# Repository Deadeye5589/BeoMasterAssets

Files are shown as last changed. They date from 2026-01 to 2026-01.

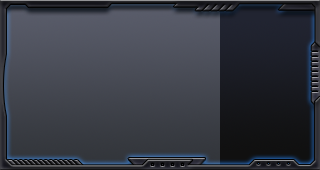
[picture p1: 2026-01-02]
SquareLineStudio/assets/Display_Left.png

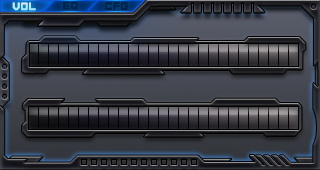
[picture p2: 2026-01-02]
SquareLineStudio/assets/Display_Right_vol_bg.png

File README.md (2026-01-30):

This repo consists of files needed for the BeoMaster Amp project.
It includes
Schematic and layout for main DSP PCB
Schematic and layout for 230 V power distribution PCB
Fusion360 and SVG files to lasercut front display construction
PDS files for left and right display graphics
Square Line Studio projects for left and right display content

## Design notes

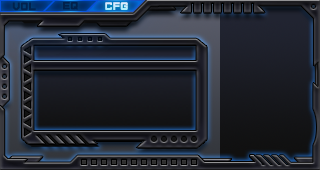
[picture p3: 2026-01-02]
SquareLineStudio/assets/Display_Right_VU_bg.png

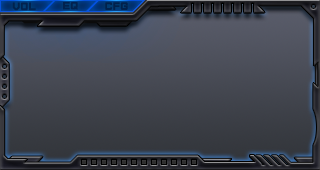
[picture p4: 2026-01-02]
SquareLineStudio/assets/Display_Right_bg.png

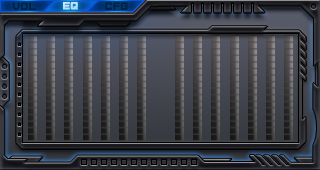
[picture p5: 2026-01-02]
SquareLineStudio/assets/Display_Right_eq_bg.png

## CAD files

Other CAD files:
CAD/Amp+Grundplatte_v3.f3d
CAD/BeoMasterBlende.f3d

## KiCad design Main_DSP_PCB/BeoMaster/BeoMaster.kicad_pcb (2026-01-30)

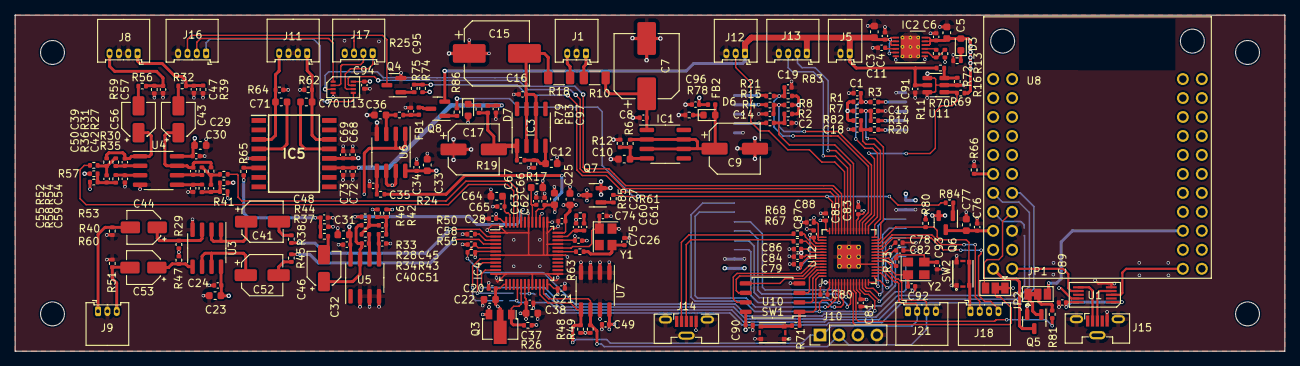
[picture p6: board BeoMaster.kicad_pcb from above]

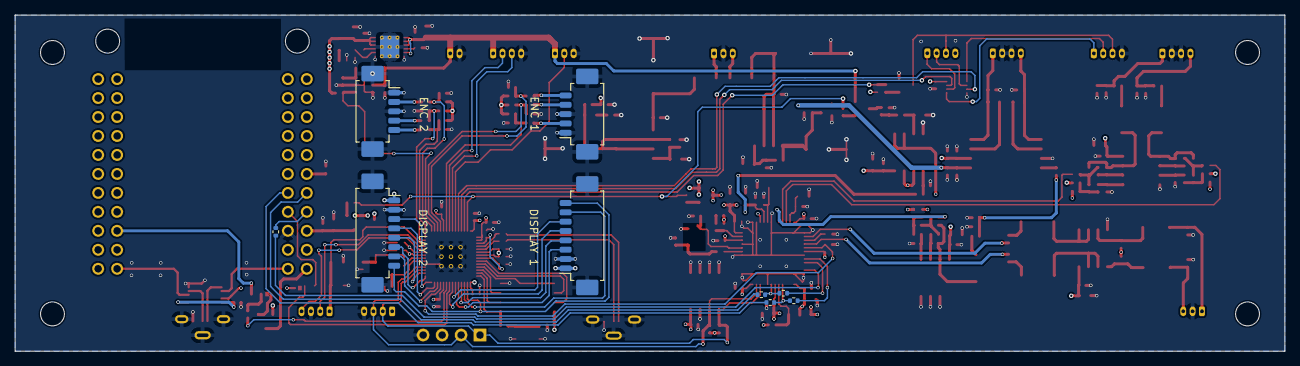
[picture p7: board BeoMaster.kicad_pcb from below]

Board: 4 copper layers, 170.0 x 45.0 mm, 238 parts (9 on the bottom side), 160 nets.

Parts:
C1, C2, C4, C6, C13, C14, C18, C19, C20, C21, C24, C26, C27, C28, C30, C32, C34, C35, C38, C49, C58, C63, C65, C67, C69, C73, C76, C89: 100nF; C_0402_1005Metric
C3, C5, C10, C12, C22, C23, C25, C29, C31, C33, C37, C62, C64, C66, C70, C71, C77: 10µF; C_0603_1608Metric
C7, C15: 220µF; CP_Elec_8x10.5
C8, C16: 220nF; C_0402_1005Metric
C9, C17: 100µF; CP_Elec_6.3x5.8
C11, C95, C96, C97: 10nF; C_0402_1005Metric
C36: 2.2µF; C_0603_1608Metric
C39, C40, C50, C51, C54, C59: 150pF; C_0402_1005Metric
C41, C52: 47µF; CP_Elec_5x5.8
C42, C45, C55: 1nF; C_0402_1005Metric
C43, C46, C56: 10µF; CP_Elec_4x5.4
C44, C53: 2.2µF; CP_Elec_4x5.4
C47, C48, C57, C60: 3n3; C_0402_1005Metric
C61: 56nF; C_0402_1005Metric
C68, C72: 1µF; C_0402_1005Metric
C74, C75: 18pF; C_0402_1005Metric
C78, C79, C80, C81, C82, C83, C84, C85, C86, C90, C91, C94: 100n; C_0402_1005Metric
C87, C88: 1u; C_0402_1005Metric
C92, C93: 18p; C_0402_1005Metric
D3, D6, D7: LED; LED_0603_1608Metric
FB1, FB2, FB3: 300@1MHz; L_0402_1005Metric
H1, H2, H3, H4: MountingHole; MountingHole_3.2mm_M3_ISO14580
IC1: LM317L_SO8; SOIC-8_3.9x4.9mm_P1.27mm
IC2: LP38798; WSON-12-1EP_4x4mm_P0.5mm_EP2.6x3mm_ThermalVias
IC3: LM337L_SO8; SOIC-8_3.9x4.9mm_P1.27mm
IC4: ADAU1701JSTZ; LQFP-48_7x7mm_P0.5mm
IC5: DRV134UA; SOIC127P1030X265-16N
J1: 24V_In; Molex_PicoBlade_53048-0310_1x03_P1.25mm_Horizontal
J2: Encoder_Links; Molex_PicoBlade_53261-0571_1x05-1MP_P1.25mm_Horizontal
J3: Encoder_Rechts; Molex_PicoBlade_53261-0571_1x05-1MP_P1.25mm_Horizontal
J4: Display_Links; Molex_PicoBlade_53261-0871_1x08-1MP_P1.25mm_Horizontal
J5: 5V_In; Molex_PicoBlade_53048-0210_1x02_P1.25mm_Horizontal
J6: Display_Rechts; Molex_PicoBlade_53261-0871_1x08-1MP_P1.25mm_Horizontal
J8: Audio_Out; Molex_PicoBlade_53048-0410_1x04_P1.25mm_Horizontal
J9: Aux_In; Molex_PicoBlade_53048-0310_1x03_P1.25mm_Horizontal
J10: DSP_Debugger; PinHeader_1x04_P2.54mm_Vertical
J11: Diff_Out; Molex_PicoBlade_53048-0410_1x04_P1.25mm_Horizontal
J12: WS2812; Molex_PicoBlade_53048-0310_1x03_P1.25mm_Horizontal
J13: 220V_Relais; Molex_PicoBlade_53048-0410_1x04_P1.25mm_Horizontal
J14: RPI_USB; USB_Micro-B_Molex-105133-0031
J15: USB_Audio; USB_Micro-B_Molex-105133-0031
J16: AMP_CTRL1; Molex_PicoBlade_53048-0410_1x04_P1.25mm_Horizontal
J17: AMP_CTRL2; Molex_PicoBlade_53048-0410_1x04_P1.25mm_Horizontal
J18: RP_SWD; Molex_PicoBlade_53048-0410_1x04_P1.25mm_Horizontal
J21: I2C_TempSensor; Molex_PicoBlade_53048-0410_1x04_P1.25mm_Horizontal
JP1, JP2: SolderJumper_3_Bridged12; SolderJumper-3_P1.3mm_Bridged12_Pad1.0x1.5mm
Q3: ZXTP25040DZTA; SOT-89-3
Q4: BC816H; SOT-23
Q5, Q6, Q7, Q8: IRLML2244; SOT-23
R1, R2, R3, R4, R7, R8, R14, R15, R20, R21, R26, R31, R34, R36, R43, R54, R58, R65, R71, R73, R75, R82, R83: 1k; R_0402_1005Metric
R6, R19, R62, R64: 220; R_0402_1005Metric
R10, R18: 100; R_1206_3216Metric
R11: 23k7; R_0402_1005Metric
R12, R17: 2k; R_0402_1005Metric
R13: 180; R_0402_1005Metric
R16: 13k3; R_0402_1005Metric
R24, R30, R33, R35, R42, R53, R55, R57, R66, R69, R70, R74, R80: 10k; R_0402_1005Metric
R25, R29, R47: 100k; R_0402_1005Metric
R27, R28, R41, R46, R52, R60: 22k; R_0402_1005Metric
R32, R37, R56: 680; R_0402_1005Metric
R38, R45, R72: 18k; R_0402_1005Metric
R39, R40, R44, R51, R59: 47k; R_0402_1005Metric
R48, R49: 2k2; R_0402_1005Metric
R50: 18k2; R_0402_1005Metric
R61: 475; R_0402_1005Metric
R63, R81, R84, R85, R86: 100; R_0402_1005Metric
R67, R68: 27; R_0402_1005Metric
R78, R79: 820; R_0402_1005Metric
R87, R88, R89, R90, R91: 22; R_0402_1005Metric
SW1: BOOT; SKSG
SW2: RESET; SKSG
U1: TS3USB30E; TEXAS_VSSOP_10_P0.5
U3, U4, U5, U6: LME49720; SOIC-8_3.9x4.9mm_P1.27mm
U7: 24LC256 (SN); SOIC-8_3.9x4.9mm_P1.27mm
U8: CSRA64215; CSR64215
U10: W25Q128JVS; SOIC-8_5.23x5.23mm_P1.27mm
U11: TPS3711; SOT-23-6
U12: RP2040; RP2040-QFN-56
U13: NC7WZ38; US8 -OnSemi
Y1: 12.288MHz; Crystal_SMD_3225-4Pin_3.2x2.5mm
Y2: 12 MHz; Crystal_SMD_3225-4Pin_3.2x2.5mm

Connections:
+1V1: C78.1, C79.1, C87.1, U12.23 (DVDD), U12.45 (VREG_VOUT), U12.50 (DVDD)
+1V5: R35.1, R42.1, R57.1, U6.6 (-), U6.7
+1V8: C20.1, C21.1, C22.1, IC4.13 (DVDD), IC4.24 (DVDD), Q3.2 (C)
+3.3VP: C25.1, C26.1, C27.1, C28.1, C37.1, C38.1, C49.1, C60.2, IC4.6 (SELFBOOT), IC4.18 (IOVDD), IC4.34 (PVDD), IC4.36 (AVDD), IC4.39 (PLL_MOD1), IC4.48 (AVDD), Q3.3 (E), Q7.3 (D), R26.1, R48.1, R49.1, R55.1, R61.1, U7.8 (VCC)
+3V3: C5.1, C6.1, C80.1, C81.1, C82.1, C83.1, C84.1, C85.1, C86.1, C88.1, C89.1, C90.1, C94.1, D3.2 (A), IC2.10 (OUT_(FB)), IC2.11 (OUT), IC2.12 (OUT), J4.1, J6.1, J21.1, Q5.2 (S), Q6.2 (S), Q7.2 (S), R1.2, R2.2, R7.2, R8.2, R69.1, R74.1, R80.1, R82.2, R83.2, U1.1 (S), U1.10 (Vcc), U10.8 (VCC), U12.1 (IOVDD), U12.10 (IOVDD), U12.22 (IOVDD), U12.33 (IOVDD), U12.42 (IOVDD), U12.43 (ADC_AVDD), U12.44 (VREG_IN), U12.48 (USB_VDD), U12.49 (IOVDD), U13.8 (Vcc)
+5V: C3.1, C4.1, C91.1, IC2.1 (IN), IC2.2 (IN), IC2.3 (IN_(CP)), IC2.5 (EN), J5.1, J12.1, J13.1, Q8.2 (S), R70.1, U11.5 (VDD)
+5VA: R29.1, R41.2, R46.2, R47.1, R60.2, U6.1, U6.2 (-)
+12V: C23.1, C24.1, C29.1, C30.1, C31.1, C32.1, C33.1, C34.1, C68.1, C69.1, C96.1, FB2.2, IC5.12 (V+), U3.8 (V+), U4.8 (V+), U5.8 (V+), U6.8 (V+)
-12V: C72.2, C73.2, C97.2, FB3.2, IC5.11 (V-)
/AMP_MUTE: R74.2, R75.2, U12.40 (GPIO28_ADC2)
/QSPI_SCLK: U10.6 (CLK), U12.52 (QSPI_SCLK)
/QSPI_SD0: U10.5 (DI(IO0)), U12.53 (QSPI_SD0)
/QSPI_SD1: U10.2 (DO(IO1)), U12.55 (QSPI_SD1)
/QSPI_SD2: U10.3 (IO2), U12.54 (QSPI_SD2)
/QSPI_SD3: U10.7 (IO3), U12.51 (QSPI_SD3)
/QSPI_SS: R71.1, U10.1 (~CS), U12.56 (QSPI_SS)
/RUN: J18.1, R80.2, SW2.2, U12.26 (RUN)
/SSR1: J13.2, U12.35 (GPIO23)
/SSR2: J13.3, U12.36 (GPIO24)
/SWCLK: J18.4, U12.24 (SWCLK)
/SWD: J18.2, U12.25 (SWD)
/USB_D+: J14.3 (D+), R67.1
/USB_D-: J14.2 (D-), R68.1
/USB_N: U1.7 (D2-), U8.2 (USBN)
/USB_P: U1.3 (D2+), U8.23 (USBP)
/V_SENS: R69.2, U11.1 (OUT), U12.30 (GPIO19)
/Vin+: J1.1, R10.1
/Vin-: J1.3, R18.1
/XIN: C92.1, U12.20 (XIN), Y2.1
/XOUT: R73.1, U12.21 (XOUT)
/~USB_BOOT: R71.2, SW1.2
AMP_MUTE_CONN: J16.3, J17.3, Q4.3 (C)
AMP_OC: U12.39 (GPIO27_ADC1), U13.7 (Y1)
AMP_TEMP: U12.38 (GPIO26_ADC0), U13.3 (Y2)
Analog_In0: IC4.45 (VOUT1), R30.1
Analog_In1: IC4.46 (VOUT0), R53.1
Analog_Out0: C47.1, J8.1, R32.2, R39.1
Analog_Out1: C57.1, J8.4, R56.2, R59.1
BCLK: R90.2, U8.9 (CLK)
BT_MFB: R81.1, U12.9 (GPIO7)
BT_RST: JP2.2 (C), U12.8 (GPIO6)
CM: C62.1, C63.1, IC4.40 (CM), R24.2
DISP_BL: J4.8, J6.8, U12.2 (GPIO0)
DISP_CLK1: J4.4, U12.13 (GPIO10)
DISP_CLK2: J6.4, U12.4 (GPIO2)
DISP_CS1: J4.5, U12.16 (GPIO13)
DISP_CS2: J6.5, U12.7 (GPIO5)
DISP_DC1: J4.6, U12.15 (GPIO12)
DISP_DC2: J6.6, U12.6 (GPIO4)
DISP_DIN1: J4.3, U12.14 (GPIO11)
DISP_DIN2: J6.3, U12.5 (GPIO3)
DISP_RST1: J4.7, U12.12 (GPIO9)
DISP_RST2: J6.7, U12.3 (GPIO1)
DSP_RESET: C58.1, IC4.5 (~RESET), J10.3, R55.2, U12.11 (GPIO8)
Diff_In0: IC4.44 (VOUT2), R33.1
Diff_Out0: C48.1, R37.2, R44.1, R65.2
Diff_Out0+: C70.1, IC5.14 (+Vo), J11.1, R62.1
Diff_Out0-: C71.2, IC5.3 (-Vo), J11.4, R64.2
ENC1_A: C13.1, R7.1, R14.2, U12.27 (GPIO16)
ENC1_B: C18.1, R20.2, R82.1, U12.28 (GPIO17)
ENC1_SW: C1.1, R1.1, R3.2, U12.29 (GPIO18)
ENC2_A: C14.1, R8.1, R15.2, U12.31 (GPIO20)
ENC2_B: C19.1, R21.2, R83.1, U12.32 (GPIO21)
ENC2_SW: C2.1, R2.1, R4.2, U12.34 (GPIO22)
GND: C1.2, C2.2, C3.2, C4.2, C5.2, C6.2, C7.2, C8.2, C9.2, C10.2, C11.2, C12.2, C13.2, C14.2, C15.1, C16.2, C17.1, C18.2, C19.2, C20.2, C21.2, C22.2, C23.2, C24.2, C25.2, C26.2, C27.2, C28.2, C29.2, C30.2, C31.2, C32.2, C33.2, C34.2, C35.2, C36.2, C37.2, C38.2, C47.2, C48.2, C49.2, C50.2, C51.2, C57.2, C58.2, C59.2, C62.2, C63.2, C64.2, C65.2, C66.2, C67.2, C68.2, C69.2, C72.1, C73.1, C74.2, C75.2, C76.2, C77.2, C78.2, C79.2, C80.2, C81.2, C82.2, C83.2, C84.2, C85.2, C86.2, C87.2, C88.2, C89.2, C90.2, C91.2, C92.2, C93.2, C94.2, C95.2, C96.2, C97.1, D7.2 (A), IC2.6 (GND_(CP)), IC2.7 (GND), IC2.13 (EP), IC4.1 (AGND), IC4.7 (ADDR0), IC4.12 (DGND), IC4.20 (ADDR1), IC4.25 (DGND), IC4.30 (RSVD), IC4.33 (PGND), IC4.37 (AGND), IC4.38 (PLL_MOD0), IC4.42 (AGND), IC5.5 (GND), J1.2, J2.1, J2.3, J2.MP, J3.1, J3.3, J3.MP, J4.2, J4.MP, J5.2, J6.2, J6.MP, J8.2, J8.3, J9.2, J10.4, J11.2, J11.3, J12.3, J13.4, J14.5 (GND), J14.6 (Shield), J15.5 (GND), J15.6 (Shield), J16.4, J18.3, J21.4, Q4.2 (E), R12.2, R13.2, R16.2, R17.1, R39.2, R40.2, R44.2, R50.2, R51.2, R59.2, R62.2, R64.1, R66.2, R72.2, R78.2, SW1.1, SW2.1, U1.5 (GND), U3.4 (V-), U4.4 (V-), U5.2 (-), U5.3 (+), U5.4 (V-), U6.4 (V-), U7.1 (A0), U7.2 (A1), U7.3 (A2), U7.4 (GND), U7.7 (WP), U8.6 (GND), U10.4 (GND), U11.2 (GND), U11.4 (GND), U11.6 (GND), U12.19 (TESTEN), U12.57 (GND), U13.4 (GND), Y1.4
LRCLK: R91.2, U8.10 (CSB)
unnamed: C15.2, C16.1, IC3.2 (VI), IC3.3 (VI), IC3.6 (VI), IC3.7 (VI), R18.2
unnamed: C39.1, C43.1, R27.1, U4.7
unnamed: C40.1, C46.1, R28.1, U5.7
unnamed: C41.2, R38.2
unnamed: C42.1, R27.2, R30.2, R31.1
unnamed: C42.2, R35.2, R36.2, R41.1
unnamed: C43.2, R32.1
unnamed: C45.1, R28.2, R33.2, R34.1
unnamed: C45.2, R42.2, R43.2, R46.1
unnamed: C46.2, R37.1
unnamed: C52.2, R45.2
unnamed: C54.1, C56.1, R52.1, U4.1
unnamed: C55.1, R52.2, R53.2, R54.1
unnamed: C55.2, R57.2, R58.2, R60.1
unnamed: C56.2, R56.1
unnamed: C61.2, R61.2
unnamed: C75.1, R63.2, Y1.3
unnamed: C93.1, R73.2, Y2.3
unnamed: C95.1, FB1.2, R25.2
unnamed: D3.1 (K), R13.1
unnamed: C9.1, D6.2 (A), FB2.1, IC1.2 (VO), IC1.3 (VO), IC1.6 (VO), IC1.7 (VO), R6.1
unnamed: D6.1 (K), R78.1
unnamed: D7.1 (K), R79.1
unnamed: C10.1, IC1.4 (ADJ), R6.2, R12.1
unnamed: C7.1, C8.1, IC1.1 (VI), R10.2
unnamed: C11.1, IC2.4 (CP)
unnamed: IC2.8 (FB), R11.2, R16.1
unnamed: IC2.9 (SET), R11.1
unnamed: C12.1, IC3.4 (ADJ), R17.2, R19.1
unnamed: C17.2, FB3.1, IC3.1 (VO), R19.2, R79.2
unnamed: IC4.2 (ADC0), R38.1
unnamed: IC4.4 (ADC1), R45.1
unnamed: IC4.3 (ADC_RES), R50.1
unnamed: C64.1, C65.1, IC4.47 (FILTA)
unnamed: C66.1, C67.1, IC4.41 (FILTD)
unnamed: C74.1, IC4.32 (MCLKI), Y1.1
unnamed: IC4.8 (MP4), R89.1
unnamed: IC4.9 (MP5), R88.1
unnamed: IC4.16 (MP10), R89.2, R91.1
unnamed: IC4.19 (MP11), R88.2, R90.1
unnamed: IC4.31 (OSCO), R63.1
unnamed: C60.1, C61.1, IC4.35 (PLL_LF)
unnamed: IC4.17 (VDRIVE), Q3.1 (B), R26.2
unnamed: C70.2, IC5.13 (+Sense)
unnamed: C71.1, IC5.4 (-Sense)
unnamed: IC5.6 (Vin), R65.1
unnamed: J2.2, R3.1
unnamed: J2.4, R14.1
unnamed: J2.5, R20.1
unnamed: J3.2, R4.1
unnamed: J3.4, R15.1
unnamed: J3.5, R21.1
unnamed: C44.2, J9.1, R40.1
unnamed: C53.2, J9.3, R51.1
unnamed: J15.3 (D+), U1.4 (D+)
unnamed: J15.2 (D-), U1.6 (D-)
unnamed: J16.1, U13.5 (A2)
unnamed: J16.2, U13.1 (A1)
unnamed: J17.1, U13.6 (B2)
unnamed: J17.2, U13.2 (B1)
unnamed: JP1.1 (A), Q5.1 (G)
unnamed: JP1.3 (B), U8.27 (MFB)
unnamed: JP1.2 (C), R81.2
unnamed: JP2.1 (A), U1.9 (~OE)
unnamed: JP2.3 (B), U8.8 (RST)
unnamed: Q4.1 (B), R75.1
unnamed: Q5.3 (D), U8.1 (VCHG)
unnamed: C76.1, C77.1, Q6.3 (D), U8.5 (VBAT)
unnamed: Q6.1 (G), R84.2
unnamed: Q7.1 (G), R85.2
unnamed: FB1.1, Q8.3 (D)
unnamed: Q8.1 (G), R86.2
unnamed: C44.1, R29.2, U3.3 (+)
unnamed: C41.1, U3.1, U3.2 (-)
unnamed: C53.1, R47.2, U3.5 (+)
unnamed: C52.1, U3.6 (-), U3.7
unnamed: C59.1, R58.1, U4.3 (+)
unnamed: C54.2, R54.2, U4.2 (-)
unnamed: C50.1, R36.1, U4.5 (+)
unnamed: C39.2, R31.2, U4.6 (-)
unnamed: C51.1, R43.1, U5.5 (+)
unnamed: C40.2, R34.2, U5.6 (-)
unnamed: C36.1, R25.1, U6.3 (+)
unnamed: C35.1, R24.1, U6.5 (+)
unnamed: R87.1, U8.7 (MISO)
unnamed: R66.1, U8.11 (SPIPCM)
unnamed: R70.2, R72.1, U11.3 (SENSE)
unnamed: R68.2, U12.46 (USB_DM)
unnamed: R67.2, U12.47 (USB_DP)
PWR_EN: R84.1, R85.1, R86.1, U12.41 (GPIO29_ADC3)
SCL: IC4.23 (SCL), J10.2, J21.3, R49.2, U7.6 (SCL), U12.18 (GPIO15)
SDA: IC4.22 (SDA), J10.1, J21.2, R48.2, U7.5 (SDA), U12.17 (GPIO14)
SDATA: IC4.11 (MP0), R87.2
WS2812: J12.2, U12.37 (GPIO25)

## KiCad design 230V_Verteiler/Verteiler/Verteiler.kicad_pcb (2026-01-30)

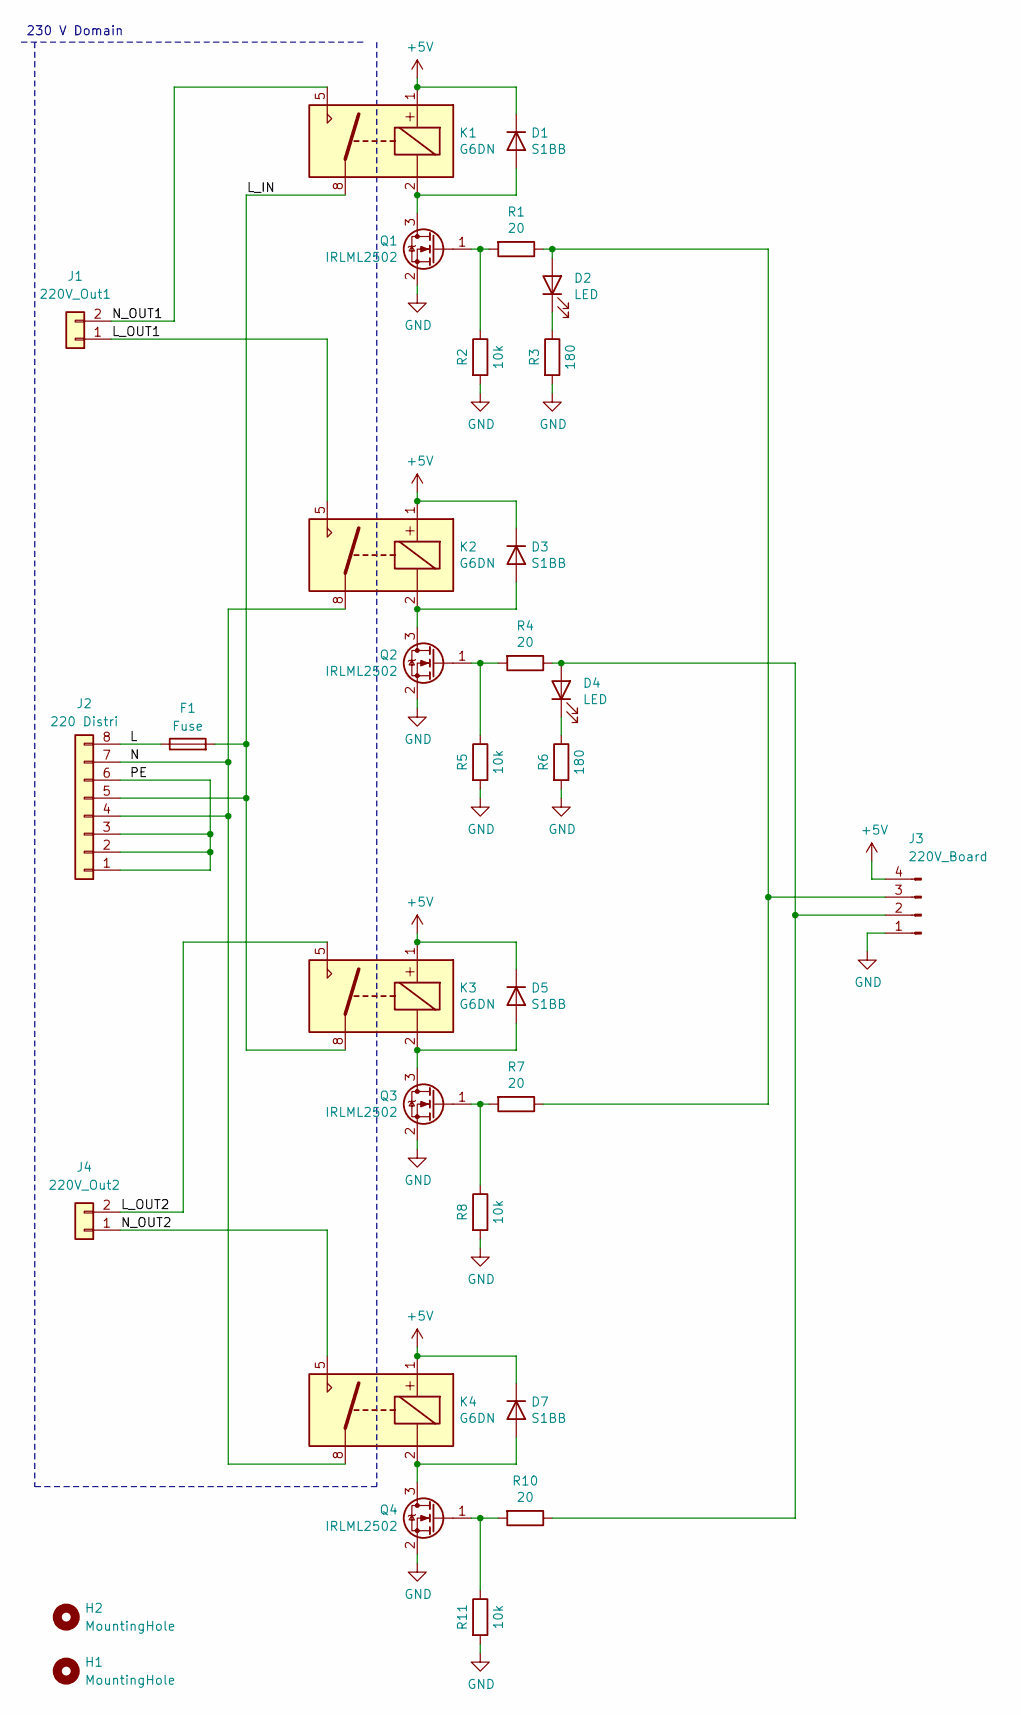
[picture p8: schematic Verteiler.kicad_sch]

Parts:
D1, D3, D5, D7: S1BB; D_SMB
D2, D4: LED; LED_0603_1608Metric
F1: Fuse; Fuseholder_Clip-5x20mm_Littelfuse_111_Lateral_P18.80x5.00mm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
H1, H2: MountingHole; MountingHole_3.2mm_M3
J1: 220V_Out1; PhoenixContact_MSTBA_2,5_2-G-5,08_1x02_P5.08mm_Horizontal
J2: 220 Distri; PhoenixContact_MSTBA_2,5_8-G-5,08_1x08_P5.08mm_Horizontal
J3: 220V_Board; Molex_PicoBlade_53048-0410_1x04_P1.25mm_Horizontal
J4: 220V_Out2; PhoenixContact_MSTBA_2,5_2-G-5,08_1x02_P5.08mm_Horizontal
K1, K2, K3, K4: G6DN
Q1, Q2, Q3, Q4: IRLML2502; SOT-23
R1, R4, R7, R10: 20; R_0402_1005Metric
R2, R5, R8, R11: 10k; R_0402_1005Metric
R3, R6: 180; R_0402_1005Metric

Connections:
+5V: D1.1 (K), D3.1 (K), D5.1 (K), D7.1 (K), J3.4, K1.1, K2.1, K3.1, K4.1
/L: F1.1, J2.8
/L_IN: F1.2, J2.5, K1.8, K3.8
/L_OUT1: J1.1, K2.5
/L_OUT2: J4.2, K3.5
/N: J2.4, J2.7, K2.8, K4.8
/N_OUT1: J1.2, K1.5
/N_OUT2: J4.1, K4.5
/PE: J2.1, J2.2, J2.3, J2.6
GND: J3.1, Q1.2 (S), Q2.2 (S), Q3.2 (S), Q4.2 (S), R2.2, R3.2, R5.2, R6.2, R8.2, R11.2
unnamed: D1.2 (A), K1.2, Q1.3 (D)
unnamed: D2.2 (A), J3.3, R1.1, R7.1
unnamed: D2.1 (K), R3.1
unnamed: D3.2 (A), K2.2, Q2.3 (D)
unnamed: D4.2 (A), J3.2, R4.1, R10.1
unnamed: D4.1 (K), R6.1
unnamed: D5.2 (A), K3.2, Q3.3 (D)
unnamed: D7.2 (A), K4.2, Q4.3 (D)
unnamed: Q1.1 (G), R1.2, R2.1
unnamed: Q2.1 (G), R4.2, R5.1
unnamed: Q3.1 (G), R7.2, R8.1
unnamed: Q4.1 (G), R10.2, R11.1

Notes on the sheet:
230 V Domain

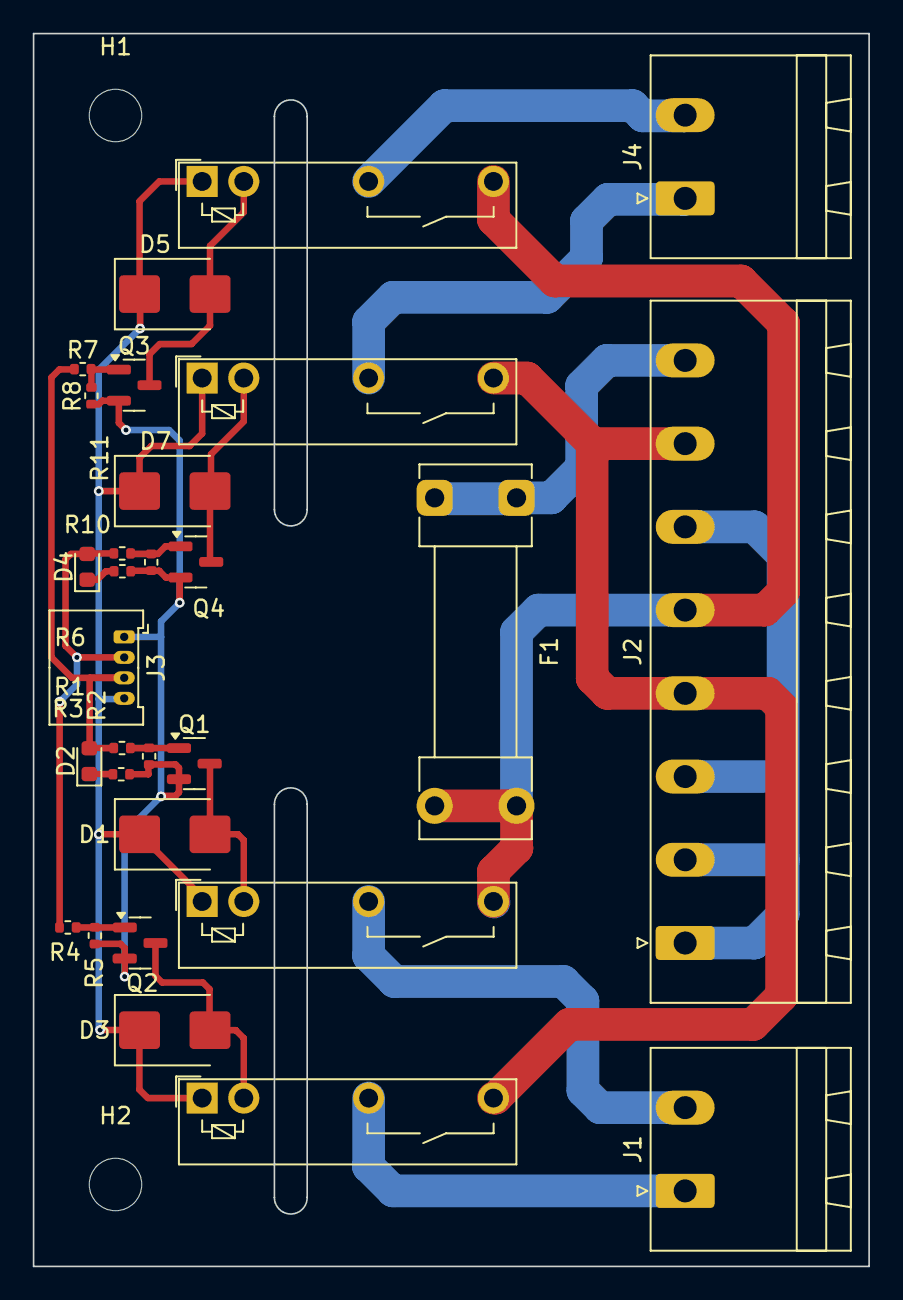
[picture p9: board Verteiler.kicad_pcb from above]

Board: 2 copper layers, 51.0 x 75.2 mm, 31 parts (0 on the bottom side), 22 nets.

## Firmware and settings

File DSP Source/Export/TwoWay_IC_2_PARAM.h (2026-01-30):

/*
 * File:           C:\Users\Succubus\Documents\KiCad\B&O Master\DSP Source\Export\TwoWay_IC_2_PARAM.h
 *
 * Created:        Thursday, December 28, 2023 4:48:27 PM
 * Description:    TwoWay:IC 2 parameter RAM definitions.
 *
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
 * This software may only be used to program products purchased from
 * Analog Devices for incorporation by you into audio products that
 * are intended for resale to audio product end users. This software
 * may not be distributed whole or in any part to third parties.
 *
 * Copyright ©2023 Analog Devices, Inc. All rights reserved.
 */
#ifndef __TWOWAY_IC_2_PARAM_H__
#define __TWOWAY_IC_2_PARAM_H__


/* Module Nx2-1 - Stereo Switch Nx2*/
#define MOD_NX2_1_COUNT                                1
#define MOD_NX2_1_DEVICE                               "IC2"
#define MOD_NX2_1_STEREOSWSLEW_ADDR                    0
#define MOD_NX2_1_STEREOSWSLEW_FIXPT                   0x00000001
#define MOD_NX2_1_STEREOSWSLEW_VALUE                   SIGMASTUDIOTYPE_INTEGER_CONVERT(1)
#define MOD_NX2_1_STEREOSWSLEW_TYPE                    SIGMASTUDIOTYPE_INTEGER

/* Module Single 2_2 - Single Volume*/
#define MOD_SINGLE2_2_COUNT                            2
#define MOD_SINGLE2_2_DEVICE                           "IC2"
#define MOD_SINGLE2_2_ALG0_GAIN1940ALGNS3_ADDR         1
#define MOD_SINGLE2_2_ALG0_GAIN1940ALGNS3_FIXPT        0x00800000
#define MOD_SINGLE2_2_ALG0_GAIN1940ALGNS3_VALUE        SIGMASTUDIOTYPE_FIXPOINT_CONVERT(1)
#define MOD_SINGLE2_2_ALG0_GAIN1940ALGNS3_TYPE         SIGMASTUDIOTYPE_FIXPOINT
#define MOD_SINGLE2_2_ALG1_GAIN1940ALGNS4_ADDR         2
#define MOD_SINGLE2_2_ALG1_GAIN1940ALGNS4_FIXPT        0x00800000
#define MOD_SINGLE2_2_ALG1_GAIN1940ALGNS4_VALUE        SIGMASTUDIOTYPE_FIXPOINT_CONVERT(1)
#define MOD_SINGLE2_2_ALG1_GAIN1940ALGNS4_TYPE         SIGMASTUDIOTYPE_FIXPOINT

/* Module 1 X RTA1 - Single Level Detector*/
#define MOD_1XRTA1_COUNT                               5
#define MOD_1XRTA1_DEVICE                              "IC2"
#define MOD_1XRTA1_ALG0_SINGLEBANDLEVELDET1TCONST_ADDR 3
#define MOD_1XRTA1_ALG0_SINGLEBANDLEVELDET1TCONST_FIXPT 0x00004EB0
#define MOD_1XRTA1_ALG0_SINGLEBANDLEVELDET1TCONST_VALUE SIGMASTUDIOTYPE_FIXPOINT_CONVERT(0.00240140490349172)
#define MOD_1XRTA1_ALG0_SINGLEBANDLEVELDET1TCONST_TYPE SIGMASTUDIOTYPE_FIXPOINT
#define MOD_1XRTA1_ALG0_SINGLEBANDLEVELDET1HOLD_ADDR   4
#define MOD_1XRTA1_ALG0_SINGLEBANDLEVELDET1HOLD_FIXPT  0x000001E0
#define MOD_1XRTA1_ALG0_SINGLEBANDLEVELDET1HOLD_VALUE  SIGMASTUDIOTYPE_INTEGER_CONVERT(480)
#define MOD_1XRTA1_ALG0_SINGLEBANDLEVELDET1HOLD_TYPE   SIGMASTUDIOTYPE_INTEGER
#define MOD_1XRTA1_ALG0_SINGLEBANDLEVELDET1DECAY_ADDR  5
#define MOD_1XRTA1_ALG0_SINGLEBANDLEVELDET1DECAY_FIXPT 0x0000071C
#define MOD_1XRTA1_ALG0_SINGLEBANDLEVELDET1DECAY_VALUE SIGMASTUDIOTYPE_FIXPOINT_CONVERT(0.000217013888888889)
#define MOD_1XRTA1_ALG0_SINGLEBANDLEVELDET1DECAY_TYPE  SIGMASTUDIOTYPE_FIXPOINT
#define MOD_1XRTA1_ALG0_SINGLEBANDLEVELDET1_ADDR       2074
#define MOD_1XRTA1_ALG0_SINGLEBANDLEVELDET1_VALUES     SIGMASTUDIOTYPE_SPECIAL(0x01CE)
#define MOD_1XRTA1_ALG0_SINGLEBANDLEVELDET1_TYPE       SIGMASTUDIOTYPE_SPECIAL
#define MOD_1XRTA1_ALG0_ADDR                           2074
#define MOD_1XRTA1_ALG0_VALUE                          SIGMASTUDIOTYPE_10_14_CONVERT(0)
#define MOD_1XRTA1_ALG0_TYPE                           SIGMASTUDIOTYPE_10_14

/* Module 1 X RTA2 - Single Level Detector*/
#define MOD_1XRTA2_COUNT                               5
#define MOD_1XRTA2_DEVICE                              "IC2"
#define MOD_1XRTA2_ALG0_SINGLEBANDLEVELDET2TCONST_ADDR 6
#define MOD_1XRTA2_ALG0_SINGLEBANDLEVELDET2TCONST_FIXPT 0x00004EB0
#define MOD_1XRTA2_ALG0_SINGLEBANDLEVELDET2TCONST_VALUE SIGMASTUDIOTYPE_FIXPOINT_CONVERT(0.00240140490349172)
#define MOD_1XRTA2_ALG0_SINGLEBANDLEVELDET2TCONST_TYPE SIGMASTUDIOTYPE_FIXPOINT
#define MOD_1XRTA2_ALG0_SINGLEBANDLEVELDET2HOLD_ADDR   7
#define MOD_1XRTA2_ALG0_SINGLEBANDLEVELDET2HOLD_FIXPT  0x000001E0
#define MOD_1XRTA2_ALG0_SINGLEBANDLEVELDET2HOLD_VALUE  SIGMASTUDIOTYPE_INTEGER_CONVERT(480)
#define MOD_1XRTA2_ALG0_SINGLEBANDLEVELDET2HOLD_TYPE   SIGMASTUDIOTYPE_INTEGER
#define MOD_1XRTA2_ALG0_SINGLEBANDLEVELDET2DECAY_ADDR  8
#define MOD_1XRTA2_ALG0_SINGLEBANDLEVELDET2DECAY_FIXPT 0x0000071C
#define MOD_1XRTA2_ALG0_SINGLEBANDLEVELDET2DECAY_VALUE SIGMASTUDIOTYPE_FIXPOINT_CONVERT(0.000217013888888889)
#define MOD_1XRTA2_ALG0_SINGLEBANDLEVELDET2DECAY_TYPE  SIGMASTUDIOTYPE_FIXPOINT
#define MOD_1XRTA2_ALG0_SINGLEBANDLEVELDET2_ADDR       2074
#define MOD_1XRTA2_ALG0_SINGLEBANDLEVELDET2_VALUES     SIGMASTUDIOTYPE_SPECIAL(0x0252)
#define MOD_1XRTA2_ALG0_SINGLEBANDLEVELDET2_TYPE       SIGMASTUDIOTYPE_SPECIAL
#define MOD_1XRTA2_ALG0_ADDR                           2074
#define MOD_1XRTA2_ALG0_VALUE                          SIGMASTUDIOTYPE_10_14_CONVERT(0)
#define MOD_1XRTA2_ALG0_TYPE                           SIGMASTUDIOTYPE_10_14
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

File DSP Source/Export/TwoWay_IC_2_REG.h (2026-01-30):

/*
 * File:           C:\Users\Succubus\Documents\KiCad\B&O Master\DSP Source\Export\TwoWay_IC_2_REG.h
 *
 * Created:        Thursday, December 28, 2023 4:48:27 PM
 * Description:    TwoWay:IC 2 control register definitions.
 *
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
 * This software may only be used to program products purchased from
 * Analog Devices for incorporation by you into audio products that
 * are intended for resale to audio product end users. This software
 * may not be distributed whole or in any part to third parties.
 *
 * Copyright ©2023 Analog Devices, Inc. All rights reserved.
 */
#ifndef __TWOWAY_IC_2_REG_H__
#define __TWOWAY_IC_2_REG_H__


/* InterfaceRegister0  - Registers (IC 2) */
#define REG_INTERFACEREGISTER0_IC_2_ADDR          0x800
#define REG_INTERFACEREGISTER0_IC_2_BYTE          4
#define REG_INTERFACEREGISTER0_IC_2_VALUE         0x0

/* InterfaceRegister1  - Registers (IC 2) */
#define REG_INTERFACEREGISTER1_IC_2_ADDR          0x801
#define REG_INTERFACEREGISTER1_IC_2_BYTE          4
#define REG_INTERFACEREGISTER1_IC_2_VALUE         0x0

/* InterfaceRegister2  - Registers (IC 2) */
#define REG_INTERFACEREGISTER2_IC_2_ADDR          0x802
#define REG_INTERFACEREGISTER2_IC_2_BYTE          4
#define REG_INTERFACEREGISTER2_IC_2_VALUE         0x0

/* InterfaceRegister3  - Registers (IC 2) */
#define REG_INTERFACEREGISTER3_IC_2_ADDR          0x803
#define REG_INTERFACEREGISTER3_IC_2_BYTE          4
#define REG_INTERFACEREGISTER3_IC_2_VALUE         0x0

/* InterfaceRegister4  - Registers (IC 2) */
#define REG_INTERFACEREGISTER4_IC_2_ADDR          0x804
#define REG_INTERFACEREGISTER4_IC_2_BYTE          4
#define REG_INTERFACEREGISTER4_IC_2_VALUE         0x0

/* InterfaceRegister5  - Registers (IC 2) */
#define REG_INTERFACEREGISTER5_IC_2_ADDR          0x805
#define REG_INTERFACEREGISTER5_IC_2_BYTE          4
#define REG_INTERFACEREGISTER5_IC_2_VALUE         0x0

/* InterfaceRegister6  - Registers (IC 2) */
#define REG_INTERFACEREGISTER6_IC_2_ADDR          0x806
#define REG_INTERFACEREGISTER6_IC_2_BYTE          4
#define REG_INTERFACEREGISTER6_IC_2_VALUE         0x0

/* InterfaceRegister7  - Registers (IC 2) */
#define REG_INTERFACEREGISTER7_IC_2_ADDR          0x807
#define REG_INTERFACEREGISTER7_IC_2_BYTE          4
#define REG_INTERFACEREGISTER7_IC_2_VALUE         0x0

/* GpioAllRegister  - Registers (IC 2) */
#define REG_GPIOALLREGISTER_IC_2_ADDR             0x808
#define REG_GPIOALLREGISTER_IC_2_BYTE             2
#define REG_GPIOALLREGISTER_IC_2_VALUE            0x0

/* Adc0  - Registers (IC 2) */
#define REG_ADC0_IC_2_ADDR                        0x809
#define REG_ADC0_IC_2_BYTE                        1
#define REG_ADC0_IC_2_VALUE                       0x0

/* Adc1  - Registers (IC 2) */
#define REG_ADC1_IC_2_ADDR                        0x80A
#define REG_ADC1_IC_2_BYTE                        1
#define REG_ADC1_IC_2_VALUE                       0x0

/* Adc2  - Registers (IC 2) */
#define REG_ADC2_IC_2_ADDR                        0x80B
#define REG_ADC2_IC_2_BYTE                        1
#define REG_ADC2_IC_2_VALUE                       0x0

/* Adc3  - Registers (IC 2) */
#define REG_ADC3_IC_2_ADDR                        0x80C
#define REG_ADC3_IC_2_BYTE                        1
#define REG_ADC3_IC_2_VALUE                       0x0

/* CoreRegister  - Registers (IC 2) */
#define REG_COREREGISTER_IC_2_ADDR                0x81C
#define REG_COREREGISTER_IC_2_BYTE                2
#define REG_COREREGISTER_IC_2_VALUE               0x1C

/* RAMRegister  - Registers (IC 2) */
#define REG_RAMREGISTER_IC_2_ADDR                 0x81D
#define REG_RAMREGISTER_IC_2_BYTE                 1
#define REG_RAMREGISTER_IC_2_VALUE                0x8

/* SerialOutRegister1  - Registers (IC 2) */
#define REG_SERIALOUTREGISTER1_IC_2_ADDR          0x81E
#define REG_SERIALOUTREGISTER1_IC_2_BYTE          2
#define REG_SERIALOUTREGISTER1_IC_2_VALUE         0x802

/* SerialInputRegister  - Registers (IC 2) */
#define REG_SERIALINPUTREGISTER_IC_2_ADDR         0x81F
#define REG_SERIALINPUTREGISTER_IC_2_BYTE         1
#define REG_SERIALINPUTREGISTER_IC_2_VALUE        0x0

/* MpCfg0  - Registers (IC 2) */
#define REG_MPCFG0_IC_2_ADDR                      0x820
#define REG_MPCFG0_IC_2_BYTE                      3
#define REG_MPCFG0_IC_2_VALUE                     0x444444

/* MpCfg1  - Registers (IC 2) */
#define REG_MPCFG1_IC_2_ADDR                      0x821
#define REG_MPCFG1_IC_2_BYTE                      3
#define REG_MPCFG1_IC_2_VALUE                     0x444444

/* AnalogPowerDownRegister  - Registers (IC 2) */
#define REG_ANALOGPOWERDOWNREGISTER_IC_2_ADDR     0x822
#define REG_ANALOGPOWERDOWNREGISTER_IC_2_BYTE     2
#define REG_ANALOGPOWERDOWNREGISTER_IC_2_VALUE    0x0

/* TestRegister  - Registers (IC 2) */
#define REG_TESTREGISTER_IC_2_ADDR                0x823
#define REG_TESTREGISTER_IC_2_BYTE                2
#define REG_TESTREGISTER_IC_2_VALUE               0x0

/* AnalogInterfaceRegister0  - Registers (IC 2) */
#define REG_ANALOGINTERFACEREGISTER0_IC_2_ADDR    0x824
#define REG_ANALOGINTERFACEREGISTER0_IC_2_BYTE    2
#define REG_ANALOGINTERFACEREGISTER0_IC_2_VALUE   0x8000

/* AnalogInterfaceRegister1  - Registers (IC 2) */
#define REG_ANALOGINTERFACEREGISTER1_IC_2_ADDR    0x825
#define REG_ANALOGINTERFACEREGISTER1_IC_2_BYTE    2
#define REG_ANALOGINTERFACEREGISTER1_IC_2_VALUE   0x0

/* AnalogInterfaceRegister2  - Registers (IC 2) */
#define REG_ANALOGINTERFACEREGISTER2_IC_2_ADDR    0x826
#define REG_ANALOGINTERFACEREGISTER2_IC_2_BYTE    2
#define REG_ANALOGINTERFACEREGISTER2_IC_2_VALUE   0x0

/* AnalogInterfaceRegister3  - Registers (IC 2) */
#define REG_ANALOGINTERFACEREGISTER3_IC_2_ADDR    0x827
#define REG_ANALOGINTERFACEREGISTER3_IC_2_BYTE    2
#define REG_ANALOGINTERFACEREGISTER3_IC_2_VALUE   0x1


/*
 *
 * Control register's field descriptions
 *
 */

/* InterfaceRegister0 (IC 2) */
#define R0_INTERFACEREGISTER0_IC_2                0x00000000 /* 00000000000000000000000000000000b	[31:0] */
#define R0_INTERFACEREGISTER0_IC_2_MASK           0xFFFFFFFF
#define R0_INTERFACEREGISTER0_IC_2_SHIFT          0

/* InterfaceRegister1 (IC 2) */
#define R1_INTERFACEREGISTER1_IC_2                0x00000000 /* 00000000000000000000000000000000b	[31:0] */
#define R1_INTERFACEREGISTER1_IC_2_MASK           0xFFFFFFFF
#define R1_INTERFACEREGISTER1_IC_2_SHIFT          0

/* InterfaceRegister2 (IC 2) */
#define R2_INTERFACEREGISTER2_IC_2                0x00000000 /* 00000000000000000000000000000000b	[31:0] */
#define R2_INTERFACEREGISTER2_IC_2_MASK           0xFFFFFFFF
#define R2_INTERFACEREGISTER2_IC_2_SHIFT          0

/* InterfaceRegister3 (IC 2) */
#define R3_INTERFACEREGISTER3_IC_2                0x00000000 /* 00000000000000000000000000000000b	[31:0] */
#define R3_INTERFACEREGISTER3_IC_2_MASK           0xFFFFFFFF
#define R3_INTERFACEREGISTER3_IC_2_SHIFT          0
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

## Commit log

2026-01-30 Dateien für die Fontblende
    Passend zu Gehäuse W215 H62 D308 (BZ2206HT)
    https://de.aliexpress.com/item/4001301808056.html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
    2x Waveshare 1.9 Inch LCD 170x320 px
    https://www.waveshare.com/1.9inch-lcd-module.htm
2026-01-30 DSP Configuration
    Complete DSP configuration for the BeoMaster Amp
    Works with SigmaStudio 4.7
    [TwoWay.params]
2026-01-30 Relais Board for BeoMaster Amp
    KiCad 9 Files for 230 V distribution PCB of BeoMaster Amp
    [Verteiler-B_Cu.gbl, Verteiler-B_Mask.gbs, Verteiler-B_Paste.gbp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]
2026-01-30 Main DSP PCB for BeoMaster Amp
    Revision 3 of the DSP PCB, now standing upright behind the displays to save space inside the housing.
    Works in combination with 230 V Distribution PCB.
    [BeoMaster-B_Cu.gbl, BeoMaster-B_Mask.gbs, BeoMaster-B_Paste.gbp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]
2026-01-30 Update and rename Complete_Construction.svg to CAD/Complete_Construction.svg
2026-01-30 Fusion 360 files of front display construction
    [BeoMasterBlende.f3d]
2026-01-30 Fusion 360 for BeoMaster Amp
    Carrier Plate for IcePower ASX Amps, Meanwell 5V power supply, main DSP PCB and 230 V distribution PCB
    [Amp+Grundplatte_v3.f3d]
